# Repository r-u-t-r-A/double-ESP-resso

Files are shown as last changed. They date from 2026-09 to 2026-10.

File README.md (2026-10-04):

# double-ESP-resso

A cheap FPV race lap timer made from **two stacked Seeed XIAO ESP32-C5
boards** and no RX5808 module.

- The **RF node** turns the ESP32-C5's own 5 GHz Wi-Fi radio into a 5.8 GHz
  analog FPV power meter, using the receive path from
  [C5VRX](https://github.com/Twotoz/C5VRX).
- The **AP node** runs a port of [PhobosLT](https://github.com/phobos-/PhobosLT):
  a 2.4 GHz Wi-Fi access point, the web UI, lap detection, voice callouts and
  RSSI calibration. Voice callouts need an offline browser voice; see
  [docs/VOICE.md](docs/VOICE.md). Races can be started and stopped from an
  ExpressLRS radio button through its TX backpack; see
  [docs/RADIO_START.md](docs/RADIO_START.md).

```
 drone VTX ~~ 5.8 GHz ~~>  [ RF node  XIAO ESP32-C5 ]  MODEM_DIAG IQ -> power -> RSSI 0-255 @ 1 kHz
                                 |  D5/D9 UART, both directions
                           [ AP node  XIAO ESP32-C5 ]  PhobosLT lap logic + web UI
 phone / laptop <~~ 2.4 GHz Wi-Fi AP "PhobosLT_xxxxxx" ~~
```

The link is **two-way**. When you pick a band and channel in the web UI, the
AP node retunes the RF node. The RF gain is set the same way, from the
Calibration tab.

> **Status: experimental, not yet validated on hardware.**
> - **Tested:** both firmwares build, and the protocol and RSSI scaling pass
>   their host tests.
> - **Not yet measured:** tuning to R1/R3/R6/R7, RSSI behaviour during gate
>   passes, and desense from the AP radio.
>
> See [docs/bring-up.md](docs/bring-up.md) for the planned checks.

## Channels

The C5 radio can only be tuned from **5180 to 5885 MHz**.

| Band | Reachable | Not reachable |
|---|---|---|
| R (RaceBand) | R1 5658, R2, R3 5732, R4, R5, R6 5843, R7 5880 | R8 5917 |
| A / B / F | all | – |
| E | E1–E5 | E6–E8 |
| L | all (5362–5621), but these are far below the 5.66 GHz bootstrap center and untested | – |

Frequencies that fall between Wi-Fi channels are reached with the same
experimental `phy_set_freq()` step that C5VRX uses.

## Hardware

- 2 × Seeed Studio XIAO ESP32-C5.
- Optional:
  - A buzzer on the AP node's D8.
  - A 1S battery on the AP node's battery pads.
  - A **WS2812B strip around the gate** on the AP node's D4, with its own
    5 V supply. See [docs/hardware.md](docs/hardware.md#ws2812b-gate-led-strip-ap-node-d4).

**Join only these four pins between the boards:** 5V, GND, D5 and D9. The RF
node streams its 40–80 MHz IQ bus out on D0–D3 and D10, and D2/D3 are
strapping pins, so a full pin-to-pin stack is not safe. See
[docs/hardware.md](docs/hardware.md).

## Repository layout

| Path | What it contains |
|---|---|
| `rf-node/` | ESP-IDF v6.0.2 app for the RF node. GPL-3.0, derived from C5VRX. |
| `ap-node/` | PlatformIO / Arduino PhobosLT fork for the AP node. MIT, from PhobosLT. |
| `common/c5link_proto.h` | The shared UART line protocol (MIT). See [docs/protocol.md](docs/protocol.md). |
| `tools/rssi_log.py` | Records and plots RF node RSSI over USB, for calibration. |
| `tests/` | Host unit tests for the protocol and the RSSI scaling. |

## Documentation

| Document | Contents |
| --- | --- |
| [docs/FLASHING.md](docs/FLASHING.md) | Step-by-step flashing of both boards |
| [docs/hardware.md](docs/hardware.md) | Wiring, board stacking and the gate LED strip |
| [docs/protocol.md](docs/protocol.md) | RF node ↔ AP node UART protocol |
| [docs/bring-up.md](docs/bring-up.md) | Hardware bring-up checklist and results |
| [docs/VOICE.md](docs/VOICE.md) | Getting voice announcements working in the browser |
| [docs/RADIO_START.md](docs/RADIO_START.md) | Starting and stopping races from an ExpressLRS radio |

## Build and flash

Step-by-step flashing instructions for both boards are in **[docs/FLASHING.md](docs/FLASHING.md)**. The commands below are a short version.

Plug in **one board at a time**; the other board is powered through the 5V link.

### RF node

The RF node is an ESP-IDF v6.0.2 app. If you don't have ESP-IDF installed, use the container:

```sh
podman run --rm -v $PWD:/project:Z -w /project/rf-node docker.io/espressif/idf:v6.0.2 idf.py build
```

With ESP-IDF installed locally:

```sh
cd rf-node && idf.py set-target esp32c5 build flash monitor
```

### AP node

The AP node builds with PlatformIO:

```sh
cd ap-node
pio run -e XIAO_C5 -t upload          # firmware
pio run -e XIAO_C5 -t uploadfs        # web UI (LittleFS)
```

The `XIAO_C5` env uses the Tasmota `platform-espressif32` 2026.05.50 build,
which ships Arduino core 3.3.8 with ESP32-C5 support. The original PhobosLT
envs (`PhobosLT`, `ESP32C3`, `ESP32S3`) are kept for reference. They currently
fail to build upstream as well, because the old AsyncTCP fork no longer
matches newer ESPAsyncWebServer releases.

### Host tests

```sh
cc -std=c99 -Wall -Wextra -Werror -I common tests/test_c5link_proto.c -o /tmp/t_proto && /tmp/t_proto
cc -std=c99 -Wall -Wextra -Werror -I rf-node/main tests/test_rssi_scale.c -lm -o /tmp/t_rssi && /tmp/t_rssi
cc -std=c99 -Wall -Wextra -Werror -I ap-node/lib/ELRSBACKPACK tests/test_elrs_msp.c -o /tmp/t_elrs && /tmp/t_elrs
cc -std=c99 -Wall -Wextra -Werror -I ap-node/lib/LEDSTRIP tests/test_ledstrip_timing.c -o /tmp/t_led && /tmp/t_led
```

## Using it

1. Power the stack and join Wi-Fi `PhobosLT_xxxxxx` (password `phoboslt`).
   Then open `http://20.0.0.1`.
2. **Configuration tab:** pick the band and channel (for example R1, R3, R6 or
   R7) and press *Save Configuration*. The *RF node* line should show
   `OK <MHz> MHz …` within a second.
3. **Calibration tab:** watch the live RSSI while you fly or carry the quad
   through the gate.
   - If the peak flat-lines at 255, lower the *RF node gain*.
   - Set *Enter* just below the gate-pass peak and *Exit* well above the
     far-away level, then save.
4. **Race tab:** press *Start Race*.

For finer calibration without the AP node, plug the RF node in over USB and run:

```sh
tools/rssi_log.py /dev/ttyACM0 --freq 5732 --gain 40 --seconds 60 -o pass.csv
tools/rssi_log.py --plot pass.csv
```

## Gate lights

With a WS2812B strip fitted, the gate shows the race state. States higher in
the table take priority.

| State | Lights |
|---|---|
| RF node link down or RF error | Purple blink |
| Lap recorded | Three white segments chase around the ring (0.6 s) |
| Race start (tone) | Bright green flash (1 s) |
| Start countdown ("Arm your quad") | Pulsing red. Times out after 15 s if the start never comes. |
| Race running | Green. White while the drone is inside the gate (RSSI ≥ Enter). |
| Idle | Breathing blue, plus an RSSI level meter that fills from *Exit* to *Enter* (useful for calibration) |
| Low battery | Short amber blip every 2 s, over any state |

The start countdown itself still runs in the browser. *Start Race* posts
`/timer/arm`, and the gate turns green when the page posts `/timer/start` at
the tone.

## How the RF node measures RSSI

The RF node brings the ESP32-C5 Wi-Fi PHY up **receive-only**, the same way as C5VRX:
- Packet AGC is disabled and a fixed gain index is forced.
- MODEM_DIAG is routed to GPIOs.
- PARLIO RX captures the Q4/I4 sample bus at 40 MS/s.

Every millisecond it:
1. Captures one 4096-sample window (about 102 µs).
2. Computes the mean I² + Q², treating each 4-bit code as the centre of its
   quantizer bucket.
3. Maps that power logarithmically to 0–255, about 10.8 counts per dB across
   the roughly 23.5 dB range available at one gain.

This is not calibrated dBm. Lap timing only needs a repeatable relative peak,
and PhobosLT's per-sample Kalman filter and enter/exit detection work on it
unchanged.

The C5VRX composite-video path is not used at all. For power measurement
there is no need for gapless sampling, demodulation or the DAC.

## Licensing

- **`rf-node/`** contains code derived from C5VRX and is licensed
  **GPL-3.0-or-later** (see `LICENSE`).
- **`ap-node/`** is derived from PhobosLT and stays **MIT**. The original
  copyright notice is kept in `ap-node/LICENSE`.
- **`common/c5link_proto.h`** is MIT, so both nodes can use it.

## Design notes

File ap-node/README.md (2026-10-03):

# AP node: PhobosLT for the double-ESP-resso RF node

This is a fork of [PhobosLT](https://github.com/phobos-/PhobosLT) at upstream
commit `142cf08`, MIT licensed. The upstream README is kept as
`UPSTREAM_README.md`.

## What the `XIAO_C5` env changes

Everything is behind `-DC5VRX_LINK`, so the upstream environments are unchanged.

- **`lib/C5LINK/`** (new): an RSSI source that reads the RF node over UART1
  (RX D5/GPIO24, TX D9/GPIO9). Its interface matches the `RX5808` class:
  - `readRssi()` returns the latest RSSI sample.
  - `handleFrequencyChange()` retunes the RF node.
  - It adds `handleGainChange()`, a non-blocking `poll()`, and link status.
  - The protocol itself is in `../common/c5link_proto.h`.
- **`lib/LAPTIMER`**: works with either source through `typedef … RssiSource`.
- **`src/main.cpp`**: runs one `LapTimer` update per 1 kHz RF sample, and
  yields every millisecond so both tasks get CPU time on the single-core C5.
- **`lib/CONFIG`**:
  - XIAO C5 pin block.
  - New `rfGain` setting. `CONFIG_VERSION` is bumped to 1, so saved settings
    reset once.
  - The default frequency is R1 (5658 MHz).
- **`lib/WEBSERVER`**:
  - The Wi-Fi AP/STA is forced to 2.4 GHz only, at 11 dBm.
  - `/status` shows an `RF Node:` line.
- **`lib/LEDSTRIP/`** (new):
  - Drives the WS2812B gate lights on `PIN_LED_STRIP` (D4) using Adafruit
    NeoPixel over RMT.
  - Renders from the background task at 50 Hz.
  - Colours depend on race state, laps, RSSI, RF link health and the battery alarm.
- **`lib/CONFIG`** also stores `ledOn`, `ledCount` and `ledBright`, with
  `CONFIG_VERSION` bumped to 2.
  - Version 3 appends `elrsOn` and the ELRS backpack UID; v2 settings are kept.
- **`lib/RACECONTROL/`** (new): runs the start countdown on the node.
  - It arms the gate, waits for the spoken lead-in plus a random 1–5 s, then
    starts the lap timer.
  - It reports `raceArm` / `raceStart` / `raceStop` as SSE events.
- **`lib/ELRSBACKPACK/`** (new, `-DELRS_BACKPACK`): starts and stops races
  from an ExpressLRS radio button via the TX backpack's ESP-NOW messages. See
  [../docs/RADIO_START.md](../docs/RADIO_START.md).
- **`lib/WEBSERVER`** adds:
  - `POST /timer/begin`, which starts the firmware countdown. `/timer/stop` also
    cancels a countdown.
  - `POST /timer/arm`, which turns the gate red during the countdown. It's kept
    for the old browser countdown.
  - In AP mode, the SoftAP runs on channel 1 as `WIFI_AP_STA`, for ESP-NOW.
- **`data/`** (web UI):
  - Shows the RF node status and an RF gain field. These appear only when
    `/config` includes `rfGain`.
  - Warns about channels the C5 can't tune.
  - LED strip settings.
  - *Start Race* posts `/timer/begin` when `/config` includes `raceCtl`, and
    otherwise runs the old browser countdown.
  - ELRS radio-start settings, shown only when `/config` includes `elrsUid`.

## Build

```sh
pio run -e XIAO_C5 -t upload
pio run -e XIAO_C5 -t uploadfs
```

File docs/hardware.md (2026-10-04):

# Hardware

The timer uses two Seeed Studio XIAO ESP32-C5 boards, stacked. One is the
**RF node** and the other is the **AP node**.

## XIAO ESP32-C5 header

| Pin | D0 | D1 | D2 | D3 | D4 | D5 | D6 | D7 | D8 | D9 | D10 |
|-----|----|----|----|----|----|----|----|----|----|----|-----|
| GPIO | 1 | 0 | 25 | 7 | 23 | 24 | 11 | 12 | 8 | 9 | 10 |

## What each board drives

The RF node:

| Pins | Use |
|---|-----|
| D0, D1, D2, D3, D10 and GPIO 3/4/5 (not on the header) | **MODEM_DIAG Q4/I4 outputs**, toggling at 40–80 MHz |
| D5 (GPIO24) | UART TX to the AP node |
| D9 (GPIO9) | UART RX from the AP node |

The AP node:

| Pins | Use |
|---|-----|
| D5 (GPIO24) | UART RX from the RF node |
| D9 (GPIO9) | UART TX to the RF node |
| D8 (GPIO8) | Optional buzzer |
| GPIO27 | User LED |
| GPIO6 / GPIO26 | Battery sense ADC / divider enable |

## Stacking rule: join 5V, GND, D5 and D9 only

When XIAO boards are stacked, each pin meets the same pin on the other board.
Joining **all** pins is not safe, for two reasons:

- The RF node's IQ bus on D0–D3 and D10 would be loaded by the AP node's pins
  and would radiate over a longer trace.
- D2 (GPIO25) and D3 (GPIO7) are ESP32-C5 strapping pins. If the AP node
  resets while the RF node is driving them, the AP node can boot in the wrong
  mode.

**Do not use D6/D7 for the link.** GPIO11/12 are the ESP32-C5 UART0 console
pins. Both chips' ROM boot logs, and the AP node's whole Arduino console, are
driven out on GPIO11. On the first hardware test this fought the RF node's
transmitter, and every link line arrived garbled.

Fit header pins only at **5V, GND, D5 and D9**, or wire those four pins
directly. Because the pins meet pin-to-pin, the UART roles cross in firmware:

```
RF node D5 (TX) ─────── D5 (RX) AP node
RF node D9 (RX) ─────── D9 (TX) AP node
RF node 5V      ─────── 5V      AP node
RF node GND     ─────── GND     AP node
```

## Power

One USB-C cable or a battery powers both boards through the 5V link.

- To flash a board, plug in **only that board's** USB cable.
- The XIAO's VBUS back-feed protection has not been verified, so don't
  connect two USB hosts at once.

## RF considerations

- The AP node runs its Wi-Fi AP on 2.4 GHz only, at 11 dBm, a few millimetres
  from a 5.8 GHz receiver. The two bands are far apart, but desense has not
  been measured yet (see `bring-up.md`).
- The RF node uses the board's own antenna path. The RF and AP boards should
  ideally use antennas pointing away from each other.

## Unverified details

- The XIAO ESP32-C5 battery-sense divider ratio and enable polarity. The
  firmware drives GPIO26 high and assumes a 1:2 divider.
- Whether the XIAO user LED is active-low. The firmware assumes it is.

## WS2812B gate LED strip (AP node, D4)

The AP node drives a single-wire RGB strip around the gate on **D4 (GPIO23)**.
D4 is not joined to the RF node.

Supported chips, selected in the web UI (Configuration tab, **LED chip** and
**LED colour order**):

| Chip | Speed | Usual colour order | Notes |
|---|---|---|---|
| WS2812B | 800 kHz | GRB | The default. 5 V, one LED per chip. |
| WS2812 | 800 kHz | GRB | Older 6-pin version, slightly different timing. |
| WS2811 (800 kHz) | 800 kHz | RGB, but varies by strip | Often 12 V strips where one chip drives a group of 3 LEDs. Set **LED count** to the number of chips, not LEDs. |
| WS2811 (400 kHz) | 400 kHz | RGB | Only for chips wired for low-speed mode. A 300-chip frame then takes 18 ms. |

If the colours are wrong, set the strip to idle (breathing blue) and change
**LED colour order** until it really is blue.

The diagram below is for a 5 V strip. For a 12 V WS2811 strip, use a 12 V supply
for the strip and keep the common ground.

```
5 V supply (+) ──┬───────────────────── strip +5V
                 └─ 1000 µF ─┐
5 V supply (−) ──┴───────────┴───────── strip GND ── AP node GND
AP node D4 ── 330 Ω ─────────────────── strip DIN
```

- **Power the strip from its own 5 V supply**, for example a buck converter
  from the flight battery. A XIAO's USB or 5V pin cannot supply it.
  - Tie the supply ground to the AP node's GND.
  - Put the capacitor right at the strip input.
- **Sizing the supply:** a 50 cm diameter gate is about 157 cm around. That is
  about 94 LEDs at 60/m, or 47 at 30/m. Each LED draws up to 60 mA at full
  white.

| Case | Current |
|---|---|
| 94 LEDs, full brightness, white | 5.6 A |
| 94 LEDs, default brightness cap 80/255, white | about 1.8 A |
| Racing green at the default cap | about 0.5 A |

  Size the supply for the brightness you configure.
- **Level shifting:** WS2812B and WS2811 need about 0.7 × their supply on the
  data line, which is 3.5 V at 5 V, so 3.3 V data is just under spec.
  - It usually works with a short data wire.
  - If the first LEDs flicker or show wrong colours, add a 74AHCT125 level
    shifter powered from 5 V.
  - Use the shifter from the start for 12 V WS2811 strips.
- **Keep it away from the RF node:** route the strip's supply and its wiring
  away from the RF node. Rerun the desense check (bring-up §3) with the strip lit.
- **Powering the XIAO stack from the strip supply:** only feed the stack's 5V
  pin from that supply when no USB cable is plugged in.

The LED chip, colour order, LED count, brightness cap and on/off switch are set
in the web UI (Configuration tab). The colour meanings are listed in `README.md`.

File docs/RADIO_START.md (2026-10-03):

# Start and stop races from an ExpressLRS radio

You can start a race with a button on your radio, so you don't have to press
*Start Race* on a laptop and then rush to put on your goggles.

- **Short press** (under 1 s): starts the race countdown. You hear "Arm your
  quad / Starting on the tone in less than five", then the tone 1–5 s later.
- **Long press** (hold for 1 s): stops the race, or cancels the countdown.

The AP node buzzer chirps when it recognises a press.

No extra receiver is needed. The ExpressLRS TX module's built-in **TX
backpack** sends the radio's *DVR Rec* switch over ESP-NOW, and the AP node
listens for it. This is the same message RotorHazard's Timer backpack uses.

## Requirements

- ExpressLRS TX firmware **2.3.0 or newer**, with a TX backpack. This covers
  most current TX modules and radios with internal ELRS, which have an
  ESP8285/ESP32 backpack chip.
- TX backpack firmware bound to a known bind phrase (step 1).
- The AP node in its own **access point mode** (the default, with no home Wi-Fi
  SSID configured). ESP-NOW from the backpack is fixed on Wi-Fi channel 1, so
  radio start doesn't work while the timer is joined to a home network.

## 1. Bind the TX backpack to your bind phrase

The timer needs the bind phrase the backpack uses. Use your normal ELRS bind
phrase, the one your TX and receivers use.

- **Flash it in:** in the ExpressLRS Configurator, open the **Backpack** tab,
  pick your TX module's backpack target, enter the **same bind phrase**, and
  flash it. On radios with internal ELRS this is usually done over Wi-Fi.
- **Or bind it:** if the backpack was flashed without a bind phrase, press
  **Bind** in the ELRS Lua script. The TX hands its own UID, which comes from
  its bind phrase, to the backpack.

## 2. Set up the button on the radio (EdgeTX)

1. Pick a free AUX channel. ELRS numbers them from channel 5: **AUX1 = CH5**,
   AUX2 = CH6, …, AUX8 = CH12.
2. **Model → Mixes**, on that channel: Source = a **momentary** switch or button,
   for example **SH** on Radiomaster radios. Weight 100, offset 0.
3. Check on the **Channel Monitor** that the channel is **-100 when released**
   and **+100 while pressed**. If it's the other way round, set the weight to
   -100.

## 3. Turn on DVR Rec in the ELRS Lua script

Open **Tools → ExpressLRS → Backpack**:

| Setting | Value |
| --- | --- |
| Backpack | **On** |
| DVR Rec | **AUX n ▲** for the channel from step 2, where ▲ = "on" when the channel is high |
| DVR Srt Dly | **0s** |
| DVR Stp Dly | **0s** |

The delays don't affect the timer, which reacts to each press straight away.
They only delay goggle DVR recording.

If **DVR Rec** uses the wrong polarity (▼), the timer sees the button as
held all the time. Every release then looks like a new hold, and races stop or
won't start. Fix it by choosing ▲ or inverting the mix in step 2.

## 4. Enter the bind phrase on the timer

1. Connect to the timer's Wi-Fi and open the web UI.
2. **Config** tab:
   - **Radio start (ELRS):** tick it.
   - **ELRS bind phrase:** type the phrase from step 1. The timer stores only
     the 6-byte UID hashed from it, never the phrase. Leave the field empty to
     keep the current UID.
3. Click **Save Configuration**. **ELRS backpack UID** now shows the address
   the timer listens on, for example `4e:04:fd:82:21:55` for the phrase `test`.
4. Open `http://20.0.0.1/status`. The line `ELRS Backpack:` should read
   `listening`.

## 5. Test

1. With the web UI open on the **Race** tab and voice enabled (see
   [VOICE.md](VOICE.md)), short-press the button on the radio.
2. The AP buzzer chirps and the gate turns red. The browser says "Arm your quad
   …", and the tone follows.
3. Hold the button for 1 s. The race stops and the browser says "Race stopped".

The web UI's *Start Race* button uses exactly the same countdown on the timer,
so the button and the radio behave the same way.

## Troubleshooting

`http://20.0.0.1/status` shows an ELRS block under `ELRS Backpack:`. The AP
node's USB serial log (460800 baud) prints the same block every 10 s. Press the
radio button a few times, reload the page, and work down the list:

| Line | What it tells you |
| --- | --- |
| `Start errors` | All three should be `0`. A non-zero `mac` or `esp_now` value means ESP-NOW couldn't start on the C5. |
| `UID … (STA MAC …, channel …)` | The STA MAC must equal the UID, and the channel must be `1`. |
| `On air` | Every ESP-NOW frame the timer hears on its channel, from any device. **0** means the backpack isn't transmitting on channel 1: check that Backpack is On, DVR Rec is set, and the TX firmware is 2.3.0 or newer. |
| `On air … last A -> B` | The backpack's real UID. If `B` differs from `UID`, the bind phrases differ: rebind the backpack or fix the phrase on the timer. |
| `Received` | Frames ESP-NOW delivered to the timer. If `On air` counts up but this stays at 0, the STA MAC override isn't taking effect. |
| `From UID` / `MSP ok` | Frames from the bound backpack, and the ones that parsed. |
| `DVR switch` | Recording-state messages. If other functions arrive (`last function`) but none of these, the DVR Rec AUX setting isn't sending. |
| `Presses` | Classified presses. If presses are counted but the race doesn't start, the timer was already running or counting down. |

## Notes and limitations

- **One message per press edge.** The backpack sends each change once, without
  repeats. If a press is missed, press again.
  - A lost "release" makes a press look long, so it can only stop or cancel a
    race, never start one by accident.
- **Goggles with a VRx backpack** bound to the same phrase also start and stop
  DVR recording on every press.
  - With a short press, recording stops again straight away. If you want DVR
    of the race, start recording in the goggles yourself.
- **AP mode only.** If a home Wi-Fi SSID is configured and the timer joins
  that network, `/status` shows `not running (AP mode only)`.
- **Wi-Fi channel.** The timer's own Wi-Fi access point is fixed on channel 1,
  to match the backpack.

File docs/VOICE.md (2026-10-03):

# Voice announcements

The web UI speaks lap times through the browser's own text-to-speech (the Web
Speech API, wrapped by `ap-node/data/articulate.min.js`). Nothing is synthesised
on the ESP32. The start tone is different: it is generated with Web Audio, so it
plays even when voice is broken.

Voice needs two things:

1. Voice turned on in the web UI, every time the page is loaded.
2. A text-to-speech voice in the browser that works **without internet**. The
   timer's Wi-Fi AP has no internet, so Chrome's online "Google …" voices stay
   silent without any error.

## 1. Turn voice on in the web UI (every device)

1. Connect to the timer's Wi-Fi and open the web UI.
2. **Config** tab, **Announcer Type**: choose **Lap Time**, **2 Consecutive
   Laps Time** or **3 Consecutive Laps Time**. **Beep** and **None** don't
   speak lap times.
3. Click **Save Configuration**.
4. Click **Enable voice**.
5. Click **Test voice**. You should hear "testing sound for pilot …, 1, 2, 3".

The **Enable voice** setting is not saved. Click it again after every page
reload, or no announcements are spoken. Until you click it, the start tone is
the only sound.

## 2. Fedora Linux, Google Chrome

Chrome on Linux only uses the system speech engine (speech-dispatcher) when it
is started with `--enable-speech-dispatcher`. Without that flag Chrome offers
only its online voices.

### 2.1 Install and check the speech engine

```sh
sudo dnf install speech-dispatcher speech-dispatcher-espeak-ng espeak-ng
spd-say -w "lap timer test"
```

You must hear "lap timer test". If you hear nothing, fix the system audio or
speech-dispatcher first. Chrome can't speak if this doesn't.

### 2.2 Start Chrome with the flag (one-off test)

1. Quit Chrome completely: close every window and check `pgrep -a chrome`
   prints nothing. Chrome ignores the flag if an instance is already running.
2. Run:

   ```sh
   google-chrome-stable --enable-speech-dispatcher
   ```

### 2.3 Make the flag permanent

The Chrome launcher (`/opt/google/chrome/google-chrome`) doesn't read a flags
file, so override the desktop launcher in your home directory instead:

```sh
mkdir -p ~/.local/share/applications
for f in google-chrome.desktop com.google.Chrome.desktop; do
  [ -f /usr/share/applications/$f ] || continue
  sed 's|^Exec=/usr/bin/google-chrome-stable|Exec=/usr/bin/google-chrome-stable --enable-speech-dispatcher|' \
    /usr/share/applications/$f > ~/.local/share/applications/$f
done
update-desktop-database ~/.local/share/applications
```

Log out and back in, or quit Chrome fully, then start it from the app menu.
Chrome updates won't overwrite these copies. To undo the change, delete the two
files from `~/.local/share/applications`.

### 2.4 Check that Chrome sees offline voices

On the timer web UI, open DevTools (F12) → **Console** and run:

```js
speechSynthesis.getVoices().filter(v => v.localService).map(v => v.name + " (" + v.lang + ")")
```

- **Non-empty list** (espeak-ng voices such as `English (America)+…`): the flag
  works. Do section 1 and test.
- **Empty list**: Chrome wasn't started with the flag. Repeat 2.2 and make sure
  no old Chrome process was still running.

To see which voice Chrome uses by default:

```js
speechSynthesis.getVoices().find(v => v.default)
```

If the default voice has `localService: false`, the web UI will still try that
online voice and stay silent while you're on the timer's Wi-Fi. If that
happens, record it in `docs/bring-up.md`; the web UI code then needs to choose
a local voice itself.

## 3. Android, Google Chrome

Chrome on Android uses the phone's text-to-speech engine. It works offline only
if the voice data for your language is downloaded.

1. **Settings → System → Languages (& input) → Text-to-speech output**. The
   path differs by manufacturer; search Settings for "text-to-speech" if you
   can't find it.
2. Set **Preferred engine** to **Speech Services by Google**. On Samsung phones
   the Samsung engine also works if its English voice is downloaded.
3. Tap the gear icon next to the engine → **Install voice data** → **English
   (United States)** (or your language), and download it. Choose a voice
   **without** a cloud/network icon.
4. Turn the **Speech rate** and **Pitch** sliders back to the middle if they were
   changed. The web UI also has its own **Announcer Rate** setting.
5. Test offline: turn on airplane mode, then turn Wi-Fi back on and connect to
   the timer's AP. Tap **Play** (or **Listen to an example**) on the
   Text-to-speech screen. If this is silent, the web UI will be too.
6. Turn up the **media** volume. Speech uses media volume, not ringer volume.
7. When Android warns "This network has no internet access", choose **Stay
   connected**. Otherwise the phone may switch to mobile data and lose the
   timer page.
8. Open the web UI in Chrome and follow section 1.

Optional check: in Chrome, open `chrome://inspect` on the laptop with the phone
connected over USB debugging, and run the console commands from section 2.4.

## 4. Quick troubleshooting

| Symptom | Cause |
| --- | --- |
| Only the start tone, no "Arm your quad" | **Enable voice** wasn't clicked after the page loaded (section 1). |
| "Arm your quad" works but no lap times | **Announcer Type** is **None** or **Beep**. |
| **Test voice** is silent on Fedora | Chrome was started without `--enable-speech-dispatcher` (section 2). |
| **Test voice** is silent on Android | No offline voice data installed, or media volume is down (section 3). |
| Voice works on home Wi-Fi but not on the timer's Wi-Fi | An online voice is in use (sections 2.4 and 3.3). |

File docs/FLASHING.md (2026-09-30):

# Flashing double-ESP-resso

The two boards run different firmware:

| Board | Firmware | Build tool |
|---|---|---|
| **AP node** | PhobosLT fork (`ap-node/`) | PlatformIO |
| **RF node** | `rf-node/` | ESP-IDF v6.0.2, via the container below |

## Before you start

- **Label the boards.** Both are identical Seeed XIAO ESP32-C5s. Put an **AP**
  and an **RF** sticker on them before flashing.
- **Plug in only the board you are flashing.** When the boards are stacked,
  the other board is powered through the 5V link. Two USB hosts must not be
  connected at the same time.
- On Linux the board appears as `/dev/ttyACM0` when it is the only one plugged
  in. Check with `ls /dev/ttyACM*`. Your user needs access to the port (the
  `dialout` group on most distros).
- Close any serial monitor on the port before flashing.

**Tools**

- [PlatformIO Core](https://docs.platformio.org/en/latest/core/installation/) (`pio`).
  It also provides `esptool`.
- To build the RF node, either:
  - [Podman](https://podman.io/) or Docker with the `docker.io/espressif/idf:v6.0.2` image, or
  - a local ESP-IDF v6.0.2 install.

All commands below run from the repository root unless a `cd` says otherwise.

## 1. AP node

PlatformIO builds the firmware and picks the files and flash addresses itself.
Run both commands: the first writes the firmware, the second writes the web UI.

```sh
cd ap-node
pio run -e XIAO_C5 -t upload   --upload-port /dev/ttyACM0   # firmware
pio run -e XIAO_C5 -t uploadfs --upload-port /dev/ttyACM0   # web UI (LittleFS)
```

<details>
<summary>What gets written, for flashing manually with esptool</summary>

Files are in `ap-node/.pio/build/XIAO_C5/`:

| Address | File |
|---|---|
| `0x2000` | `bootloader.bin` |
| `0x8000` | `partitions.bin` |
| `0xe000` | `boot_app0.bin` (from the Arduino core: `~/.platformio/packages/framework-arduinoespressif32/tools/partitions/boot_app0.bin`) |
| `0x10000` | `firmware.bin` |
| `0x670000` | `littlefs.bin` (built with `pio run -e XIAO_C5 -t buildfs`) |

Flash mode is DIO, flash size is 8 MB and flash frequency is 80 MHz. The
partition layout is Arduino `default_8MB.csv`.

</details>

**Check the AP node**

1. Press **RESET**.
2. A Wi-Fi network `PhobosLT_xxxxxx` appears. The password is `phoboslt`.
3. Join it and open `http://20.0.0.1`.

The *RF node* line shows `DOWN`, and a connected LED strip blinks purple,
until the RF node is flashed and stacked. That is expected at this stage.

After the first flash, and after any firmware that changes the config format,
the saved settings reset to defaults once.

## 2. RF node

Unplug the AP node and plug in the RF node.

> **Enter download mode by hand.** While the RF node firmware is running, its
> USB serial port does not respond (see *Known issue* below), so esptool's
> automatic reset fails with `Write timeout`. Before every RF node flash:
> hold **BOOT**, tap **RESET** (or replug USB), then release BOOT.

**Build.** Pick the command for your setup:

```sh
# with Podman (use `docker` instead of `podman` for Docker)
podman run --rm -v $PWD:/project:Z -w /project/rf-node docker.io/espressif/idf:v6.0.2 idf.py build

# or with a local ESP-IDF v6.0.2
cd rf-node && idf.py set-target esp32c5 build && cd ..
```

**Flash.** This uses the esptool bundled with PlatformIO:

```sh
cd rf-node
~/.platformio/penv/bin/python -m esptool --chip esp32c5 -p /dev/ttyACM0 -b 921600 \
  --before no_reset --after watchdog_reset \
  write_flash --flash_mode dio --flash_size 8MB --flash_freq 80m \
  0x2000  build/bootloader/bootloader.bin \
  0x8000  build/partition_table/partition-table.bin \
  0x10000 build/rf-node.bin
```

With a local ESP-IDF you can run `idf.py -p /dev/ttyACM0 flash` from `rf-node/`
instead.

Use the underscore spelling (`write_flash`, `--flash_mode`) shown above.
PlatformIO may install esptool v4 or v5 depending on which platform ran last,
and only the underscore form works in both.

| Address | File (in `rf-node/build/`) |
|---|---|
| `0x2000` | `bootloader/bootloader.bin` |
| `0x8000` | `partition_table/partition-table.bin` |
| `0x10000` | `rf-node.bin` |

The same list is in `rf-node/build/flasher_args.json` after a build.

`--after watchdog_reset` starts the new firmware straight away. Pressing
RESET afterwards works too.

**Check the RF node** through the AP node (step 3): the web UI's *RF node*
line must show `OK <MHz> MHz gain <g> fw 1 samples …`, with `samples`
climbing by about 1000 per second.

**Known issue: the RF node's USB console.** On the first hardware test
(2026-09-30) the RF node sent nothing over USB and never read input, even
before any radio code ran and with the official USB-Serial-JTAG driver
installed. The node itself runs normally; its boot trace in NVS showed that.
This is still being investigated. Until it is fixed, `tools/rssi_log.py` and
the console commands below do not work; use the AP node's Calibration tab.

Console commands (for when USB works):

| Command | Action |
|---|---|
| `f <mhz>` | Tune |
| `g <gain>` | Set fixed gain (0–89) |
| `r` | Toggle the RSSI CSV stream (used by `tools/rssi_log.py`) |
| `d` | Diagnostics: boot stage and capture counters |
| `t` | Boot trace saved in NVS |

## 3. Stack and run

1. Join only **5V, GND, D5 and D9** between the boards (see `docs/hardware.md`).
2. Power the stack from **one** USB cable, or from the battery.
3. Open `http://20.0.0.1`. Within about a second the *RF node* line changes to
   `OK 5658 MHz gain 40 …`.

Continue with `docs/bring-up.md` for the hardware checks.

## Troubleshooting

- **No serial port, or the connection fails:**
  1. Hold **BOOT**.
  2. Tap **RESET**, or replug the USB cable while holding BOOT.
  3. Release BOOT and run the flash command again.

  Press RESET afterwards to start the new firmware.
- **Port is busy:** close `pio device monitor`, `idf.py monitor` or any other
  serial terminal.
- **Permission denied on `/dev/ttyACM0`:** add your user to the `dialout`
  group, then log out and back in.
- **Wiping a board completely**, for example one that previously ran other
  firmware: add this before flashing:

  ```sh
  ~/.platformio/penv/bin/python -m esptool --chip esp32c5 -p /dev/ttyACM0 erase_flash
  ```

  This also clears the RF node's saved channel and gain, and the AP node's settings.
- **`Handler did not handle the request` at `http://20.0.0.1`:** the web UI
  filesystem did not mount. The serial log shows `Mounting LittleFS failed`.
  - The ESP32-C5 Arduino core only mounts LittleFS **disk version 2.0**, and
    the platform builds 2.1 images by default. `targets/XIAO_C5.ini` sets
    `board_build.littlefs_version = 2.0`.
  - Pull the latest repo and run the `uploadfs` step again.
- **Web UI missing or showing old pages** after an AP firmware update: run the
  `uploadfs` step again.
- **RF node shows `DOWN` in the web UI:**
  - **UART wiring:** the roles are crossed **in firmware**, so do **not**
    cross the wires. Connect D5 to D5 and D9 to D9, straight through, the same
    way stacked headers line up.
  - **RF node firmware:** check it on its own over USB (`s` must reply
    `STATUS,…`).
  - **Power:** check that the boards share GND and 5V.

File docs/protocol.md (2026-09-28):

# RF node ↔ AP node UART protocol

The protocol is defined in [`common/c5link_proto.h`](../common/c5link_proto.h)
and tested in [`tests/test_c5link_proto.c`](../tests/test_c5link_proto.c).

## Framing

- UART runs at 921600 baud, 8N1, with no flow control.
- Messages are ASCII lines: `<payload>*<HH>\n`.
- `HH` is the upper-case hex XOR of all payload bytes, as in NMEA.
- The receiver drops lines that fail the checksum or have a bad field, and
  resynchronises on the next `\n`.

## Messages

| Direction | Line | Meaning |
|---|---|---|
| RF → AP | `R,<seq>,<rssi>` | One RSSI sample: `seq` 0–255 wraps, `rssi` 0–255. Sent at 1 kHz, about 14 bytes each, so ~140 kbit/s. |
| RF → AP | `S,<mhz>,<gain>,<state>,<fw>` | Status. Sent on boot, after every command, and once a second as a heartbeat. |
| AP → RF | `F,<mhz>` | Tune. The RF node accepts 5180–5885 MHz. |
| AP → RF | `G,<gain>` | Fixed RX gain index, 0–89. |
| AP → RF | `Q` | Ask for status. |

`<state>` is one of the following:

| State | Meaning |
|---|---|
| `OK` | Measuring on `<mhz>`. |
| `TUNING` | A retune is in progress. No `R` lines are sent. |
| `ERR_FREQ` | The requested frequency is outside the tunable window. The RF node stays on `<mhz>` but sends no `R` lines, so a wrong channel is never timed. |
| `ERR_RF` | The PHY retune failed. |

Example:

```
R,17,142*63
S,5732,40,OK,1*61
F,5843*60
```

## Ownership and recovery

- **The AP node owns the configuration.** The frequency and gain are stored in
  its PhobosLT config, set from the web UI.
- **The AP node resends until the RF node agrees.** Its `parallelTask` compares
  them with the last `S` line and resends `F` or `G` every 250 ms until they
  match. After `ERR_FREQ` or `ERR_RF` it backs off to every 2 s.
  - If the RF node reboots, the AP node reapplies the settings within about 1 s.
- **The RF node remembers its last settings.** It saves the last good
  frequency and gain in NVS, so it keeps measuring without an AP node, for
  example for USB calibration.
- **Lost samples are counted.** Gaps in `seq` are counted as dropped samples.
  They appear with the link state on the web UI's *RF node* line (`/status`).

## Timing

- The AP node runs one PhobosLT `LapTimer` update per received `R` sample. The
  Kalman filter therefore always sees a fixed 1 kHz input rate, and the
  lap-timer loop's own speed doesn't matter.
- Peak times are taken from the AP node's `millis()` when a sample is
  processed. UART transport and batching add a nearly constant 1–2 ms, which
  cancels out of lap times because each lap is measured peak to peak.

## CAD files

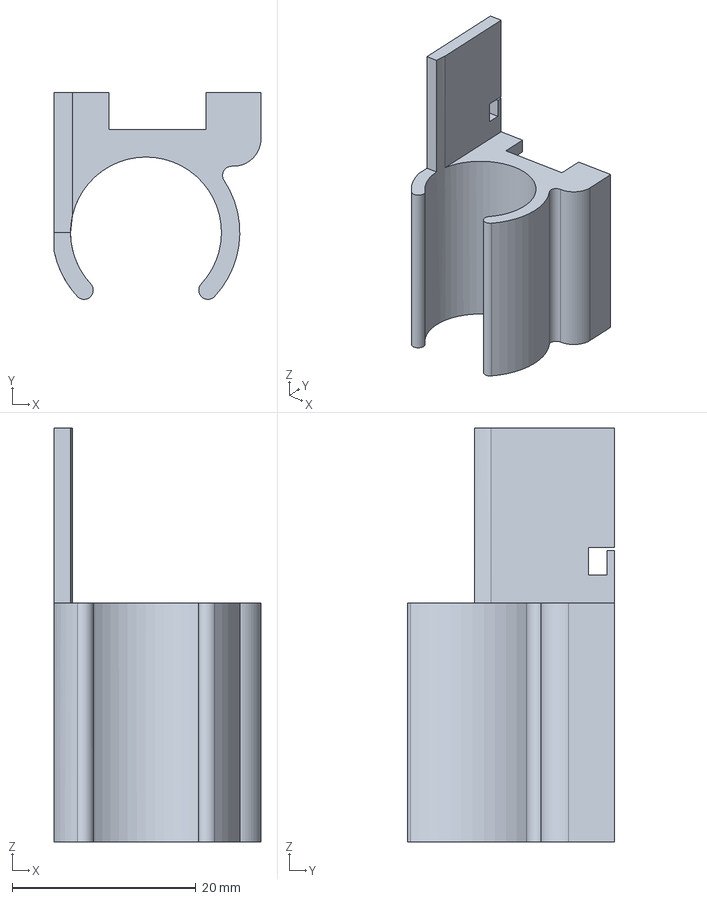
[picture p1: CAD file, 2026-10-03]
double-ESP-resso.FCStd
22.5 x 22.5 x 45.0 mm

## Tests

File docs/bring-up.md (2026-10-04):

# Hardware bring-up checklist

Record the results here (with dates) as they are measured.

## Results so far

**2026-09-30, first hardware session**
- **AP node:**
  - The web UI failed until the LittleFS image was built as disk version 2.0.
  - The link initially failed because D6/D7 carry the C5's UART0 console on
    both boards. It was moved to D5/D9.
- **RF node:**
  - **Capture:** the finite per-sample PARLIO receive starved the CPU after
    the first capture. It was replaced with C5VRX's interrupt-free continuous
    ring.
  - **Memory:** the MAC dump window 0x40830000–0x4083FFFF is now reserved
    from the heap.
- **Link:** works. The AP shows `OK 5880 MHz gain 40 fw 1`, with about 1000
  samples/s and no drops after startup.
- **RSSI:** reads 0 with no transmitter on the channel. It responds with a VTX
  on the channel and more gain ("works somewhat"). It is not calibrated yet.
- **Open issue:** the RF node's USB console stays silent (see [FLASHING.md](FLASHING.md)).

## 1. RF node alone (USB)

- [ ] Flash the RF node. The boot log shows `RF ready: <MHz> MHz, gain <g>` and `RF node v1 running`.
- [ ] Type `s` and check the reply `STATUS,<mhz>,<gain>,OK,1`.
- [ ] Tune each channel with a VTX powered on nearby. Each must reply `OK` and the RSSI must rise with the VTX on:
  - [ ] `f 5658` (R1)
  - [ ] `f 5732` (R3)
  - [ ] `f 5843` (R6)
  - [ ] `f 5880` (R7)
- [ ] `f 5917` (R8) must reply `ERR_FREQ`.
- [ ] Measure the noise floor with no VTX: `tools/rssi_log.py … --seconds 20`. Record the RSSI mean and spread.
- [ ] Take gate-pass traces at several gains (for example 20 / 30 / 40 / 50). Pick the default gain where:
  - the pass peak stays below 255 and clipping stays low;
  - the far-away level is well above the noise floor.
- [ ] Adjacent channel: with the node on R3 and a second VTX on R1 or R4 at the gate, the R3 RSSI must not reach the enter threshold.
- [ ] If a finite PARLIO receive fails or times out (`iq_power_measure` errors), switch to C5VRX's infinite-ring capture instead: `get_completed_rx_sample_window()` in C5VRX `main/video.c`.

## 2. UART link (both boards stacked)

- [ ] The AP `/status` page shows `RF Node: OK 5658 MHz gain 40 …`.
- [ ] Change the channel in the web UI and save. The RF node retunes, which `/status` confirms.
- [ ] Reset only the RF node. The AP node reapplies the frequency and gain within about 1 s.
- [ ] With the Calibration tab open for 60 s, the `dropped` count stays at 0.

## 3. Coexistence

- [ ] Compare RF node noise-floor and gate-pass RSSI with the AP Wi-Fi idle and with a phone streaming the Calibration tab.
- [ ] If the AP radio desenses the receiver, lower `C5VRX_AP_TX_POWER` in `ap-node/lib/CONFIG/config.h`.

## 4. Gate LED strip

- [ ] Power the strip from its own 5 V supply. The idle state shows breathing blue.
- [ ] Set the LED count in the web UI. The whole ring lights, with no stale pixels past the end.
- [ ] Select the strip's **LED chip** and **colour order**. Idle shows pure blue, and the countdown shows pure red.
- [ ] With a phone streaming the Calibration tab (heavy Wi-Fi traffic), the ring shows no flicker or wrong-colour pixels toward its far end. That would mean RMT underruns.
- [ ] Press *Start Race*: the gate pulses red during the countdown and flashes green at the tone.
- [ ] Carry a VTX through the gate:
  - [ ] Idle: the meter fills.
  - [ ] Race running: the ring turns white while inside, and the lap chase plays.
- [ ] Unplug the RF node: the gate blinks purple within about 3 s.
- [ ] Repeat the desense check from §3 with the strip lit at the chosen brightness.

## 5. ELRS radio start

See [RADIO_START.md](RADIO_START.md) for the radio and backpack setup.

- [ ] In AP mode with *Radio start* on and a bind phrase saved, `/status` shows `ELRS Backpack: listening`.
  - [ ] If it doesn't, check the serial log for `ELRS:` errors. The STA MAC override (`esp_wifi_set_mac`) in `WIFI_AP_STA` mode and `esp_now_init` are the unproven steps on the C5 core.
  - [ ] Check whether the log says the STA protocol with `WIFI_PROTOCOL_LR` failed. If it did, record whether frames still arrive with b/g/n only.
- [ ] Phones and laptops still join the AP, and the web UI works, while ESP-NOW is listening on channel 1.
- [ ] A short press on the radio button starts the countdown, and a 1 s hold stops it, at gate distance and at the far end of the track.
- [ ] Count missed presses over 20 presses at the pilot's position.
- [ ] Repeat the RF node noise-floor check from §3 with ESP-NOW listening.

## 6. Field

- [ ] Tune the enter/exit thresholds and minimum lap time.
- [ ] Compare lap times against video frame timing. The target is ±100 ms.
- [ ] Confirm the XIAO battery-sense scaling (GPIO6/GPIO26) against a multimeter.

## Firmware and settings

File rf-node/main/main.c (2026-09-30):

/*
 * main.c - double-ESP-resso RF node.
 *
 * Measures 5.8 GHz carrier power on one FPV channel at 1 kHz and streams it
 * to the AP node over UART. The AP node owns the configuration; this node
 * stores the last frequency/gain in NVS so it keeps measuring on its own.
 *
 * SPDX-License-Identifier: GPL-3.0-or-later
 */
#include <stdio.h>

#include "esp_log.h"
#include "esp_timer.h"
#include "freertos/FreeRTOS.h"
#include "freertos/semphr.h"
#include "freertos/task.h"
#include "nvs.h"
#include "nvs_flash.h"

#include "node.h"
#include "rf_frontend.h"

#define DEFAULT_MHZ  5658u /* R1 */
#define RF_BOOT_MHZ  5865u /* Wi-Fi ch173: no phy_set_freq() needed */
#define DEFAULT_GAIN 40u
#define SAMPLE_PERIOD_MS 1u

static const char *TAG = "node";

/* Serializes PHY retune/gain writes against capture. */
static SemaphoreHandle_t s_rf_lock;
static volatile c5link_state_t s_state = C5LINK_ST_OK;

static volatile const char *s_stage = "reset";
static volatile uint32_t s_measure_ok;
static volatile uint32_t s_measure_err;
static volatile int s_last_err;

static nvs_handle_t s_trace = 0;
/* Non-zero when the previous boot hung inside a retune to this frequency. */
static uint16_t s_prev_hang_mhz;

void node_trace(const char *key)
{
    if (!s_trace) return;
    (void)nvs_set_u32(s_trace, key, (uint32_t)(esp_timer_get_time() / 1000));
    (void)nvs_commit(s_trace);
}

void node_trace_dump(void)
{
    printf("TRACE,prev_hang_mhz=%u\n", s_prev_hang_mhz);
    nvs_iterator_t it = NULL;
    esp_err_t res = nvs_entry_find(NVS_DEFAULT_PART_NAME, "trace", NVS_TYPE_ANY, &it);
    while (res == ESP_OK) {
        nvs_entry_info_t info;
        nvs_entry_info(it, &info);
        uint32_t u = 0;
        int32_t i = 0;
        uint16_t h = 0;
        if (nvs_get_u32(s_trace, info.key, &u) == ESP_OK)
            printf("TRACE,%s=%lu\n", info.key, (unsigned long)u);
        else if (nvs_get_i32(s_trace, info.key, &i) == ESP_OK)
            printf("TRACE,%s=%ld\n", info.key, (long)i);
        else if (nvs_get_u16(s_trace, info.key, &h) == ESP_OK)
            printf("TRACE,%s=%u\n", info.key, h);
        res = nvs_entry_next(&it);
    }
    nvs_release_iterator(it);
}

/* Retune guard: a flag in flash survives a hang, so the next boot knows the
 * previous retune never returned and does not repeat it automatically. */
static esp_err_t guarded_tune(uint16_t mhz)
{
    if (s_trace) {
        (void)nvs_set_u16(s_trace, "tuning", mhz);
        (void)nvs_commit(s_trace);
    }
    esp_err_t err = rf_frontend_tune(mhz);
    if (s_trace) {
        (void)nvs_erase_key(s_trace, "tuning");
        (void)nvs_commit(s_trace);
    }
    return err;
}

static void stage(const char *name)
{
    s_stage = name;
    ESP_LOGI(TAG, "boot: %s", name);
}

void node_diag(node_diag_t *out)
{
    out->stage = (const char *)s_stage;
    out->measure_ok = s_measure_ok;
    out->measure_err = s_measure_err;
    out->last_err = s_last_err;
}

static portMUX_TYPE s_latest_mux = portMUX_INITIALIZER_UNLOCKED;
static iq_power_t s_latest;
static uint32_t s_count;

static void settings_load(uint16_t *mhz, uint8_t *gain)
{
    *mhz = DEFAULT_MHZ;
    *gain = DEFAULT_GAIN;
    nvs_handle_t h;
    if (nvs_open("rfnode", NVS_READONLY, &h) != ESP_OK) return;
    uint16_t m;
    uint8_t g;
    if (nvs_get_u16(h, "mhz", &m) == ESP_OK && rf_frontend_can_tune(m)) *mhz = m;
    if (nvs_get_u8(h, "gain", &g) == ESP_OK && g <= C5LINK_MAX_GAIN) *gain = g;
    nvs_close(h);
}

static void settings_save(void)
{
    nvs_handle_t h;
    if (nvs_open("rfnode", NVS_READWRITE, &h) != ESP_OK) return;
    (void)nvs_set_u16(h, "mhz", rf_frontend_mhz());
    (void)nvs_set_u8(h, "gain", rf_frontend_gain());
    (void)nvs_commit(h);
    nvs_close(h);
}

void node_status(c5link_msg_t *status)
{
    *status = (c5link_msg_t){
        .type = C5LINK_MSG_STATUS,
        .mhz = rf_frontend_mhz(),
        .gain = rf_frontend_gain(),
        .state = s_state,
        .version = NODE_FW_VERSION,
    };
}

void node_apply(const c5link_msg_t *cmd, c5link_msg_t *status)
{
    switch (cmd->type) {
    case C5LINK_MSG_FREQ:
        if (!rf_frontend_can_tune(cmd->mhz)) {
            s_state = C5LINK_ST_ERR_FREQ;
            break;
        }
        if (cmd->mhz == rf_frontend_mhz() && s_state == C5LINK_ST_OK) break;
        xSemaphoreTake(s_rf_lock, portMAX_DELAY);
        s_state = C5LINK_ST_TUNING;
        esp_err_t err = guarded_tune(cmd->mhz);
        s_state = err == ESP_OK ? C5LINK_ST_OK : C5LINK_ST_ERR_RF;
        xSemaphoreGive(s_rf_lock);
        if (err == ESP_OK) settings_save();
        else ESP_LOGE(TAG, "tune %u failed: %s", cmd->mhz, esp_err_to_name(err));
        break;
    case C5LINK_MSG_GAIN:
        if (cmd->gain == rf_frontend_gain()) break;
        xSemaphoreTake(s_rf_lock, portMAX_DELAY);
        rf_frontend_set_gain(cmd->gain);
        xSemaphoreGive(s_rf_lock);
        settings_save();
        break;
    default:
        break;
    }
    node_status(status);
}

bool node_latest(iq_power_t *out, uint32_t *count)
{
    taskENTER_CRITICAL(&s_latest_mux);
    *out = s_latest;
    *count = s_count;
    taskEXIT_CRITICAL(&s_latest_mux);
    return *count != 0;
}

static void measure_task(void *arg)
{
    (void)arg;
    uint8_t seq = 0;
    TickType_t wake = xTaskGetTickCount();
    for (;;) {
        vTaskDelayUntil(&wake, pdMS_TO_TICKS(SAMPLE_PERIOD_MS));
        /* Skip samples while a retune/gain write owns the PHY, like the
         * RX5808 returning 0 during its tune time. */
        if (xSemaphoreTake(s_rf_lock, 0) != pdTRUE) continue;
        iq_power_t p;
        esp_err_t err = iq_power_measure(&p);
        xSemaphoreGive(s_rf_lock);
        if (err != ESP_OK) {
            s_measure_err = s_measure_err + 1;
            s_last_err = err;
            if (s_measure_err == 1) {
                node_trace("t51_meas_err");
                if (s_trace) (void)nvs_set_i32(s_trace, "t52_err_code", err);
            }
            continue;
        }
        s_measure_ok = s_measure_ok + 1;
        if (s_measure_ok == 1) node_trace("t50_meas_ok");
        if (s_measure_ok == 5000) node_trace("t53_meas_5k");
        if (s_state != C5LINK_ST_OK) continue;

        taskENTER_CRITICAL(&s_latest_mux);
        s_latest = p;
        ++s_count;
        taskEXIT_CRITICAL(&s_latest_mux);

        c5link_msg_t m = {.type = C5LINK_MSG_RSSI, .seq = seq++, .rssi = p.rssi};
        link_send(&m);
    }
}

void app_main(void)
{
    s_rf_lock = xSemaphoreCreateMutex();
    configASSERT(s_rf_lock);

    /* Console first: it must answer even if RF bring-up stalls. */
    console_start();
    stage("nvs");
    esp_err_t err = nvs_flash_init();
    if (err == ESP_ERR_NVS_NO_FREE_PAGES || err == ESP_ERR_NVS_NEW_VERSION_FOUND) {
        ESP_ERROR_CHECK(nvs_flash_erase());
        err = nvs_flash_init();
    }
    ESP_ERROR_CHECK(err);
    if (nvs_open("trace", NVS_READWRITE, &s_trace) == ESP_OK) {
        if (nvs_get_u16(s_trace, "tuning", &s_prev_hang_mhz) == ESP_OK) {
            /* Keep the previous boot's trace for 't', drop only the flag. */
            (void)nvs_erase_key(s_trace, "tuning");
            (void)nvs_commit(s_trace);
            ESP_LOGE(TAG, "previous boot hung retuning to %u MHz", s_prev_hang_mhz);
        } else {
            (void)nvs_erase_all(s_trace);
            node_trace("t02_nvs");
        }
    }

    uint16_t mhz;
    uint8_t gain;
    settings_load(&mhz, &gain);
    /* Bring RF up on the plain Wi-Fi center first; the saved channel may need
     * the experimental phy_set_freq() step, which runs last (boot_tune) so a
     * failure there cannot keep the console and link from starting. */
    stage("rf_frontend_start");
    ESP_ERROR_CHECK(rf_frontend_start(RF_BOOT_MHZ, gain));
    node_trace("t30_rf_ok");

    stage("iq_power_init");
    ESP_ERROR_CHECK(iq_power_init());
    node_trace("t31_iq_ok");

    stage("link_start");
    link_start();
    stage("running");
    node_trace("t40_running");
    xTaskCreate(measure_task, "measure", 4096, NULL, 5, NULL);

    if (s_prev_hang_mhz) {
        /* Stay on the bootstrap center; the AP can still request a retune. */
        s_state = C5LINK_ST_ERR_RF;
    } else if (mhz != rf_frontend_mhz()) {
        stage("boot_tune");
        c5link_msg_t tune = {.type = C5LINK_MSG_FREQ, .mhz = mhz}, status;
        node_apply(&tune, &status);
        stage("running");
    }
    ESP_LOGI(TAG, "RF node v%u running: %u MHz gain %u", NODE_FW_VERSION,
             rf_frontend_mhz(), rf_frontend_gain());
}

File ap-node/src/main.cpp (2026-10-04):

#include "debug.h"
#include "led.h"
#include "webserver.h"
#include <ElegantOTA.h>

#ifdef C5VRX_LINK
static C5Link rx(PIN_C5LINK_RX, PIN_C5LINK_TX);
#else
static RX5808 rx(PIN_RX5808_RSSI, PIN_RX5808_DATA, PIN_RX5808_SELECT, PIN_RX5808_CLOCK);
#endif
static Config config;
static Webserver ws;
static Buzzer buzzer;
static Led led;
static LapTimer timer;
static BatteryMonitor monitor;
#ifdef C5VRX_LINK
static RaceControl race;
#endif
#ifdef ELRS_BACKPACK
static ElrsBackpack elrs;

// Short press starts the countdown, long press stops or cancels it.
static void handleRadioButton(uint32_t currentTimeMs) {
    elrs_press_e press = elrs.handle(currentTimeMs, config.getElrsEnabled(), config.getElrsMac());
    elrs.debugStats(currentTimeMs);
    if (press == ELRS_PRESS_SHORT && race.isIdle()) {
        buzzer.beep(60);
        race.requestBegin();
    } else if (press == ELRS_PRESS_LONG && !race.isIdle()) {
        buzzer.beep(60);
        race.requestStop();
    }
}
#endif
#ifdef PIN_LED_STRIP
static LedStrip ledStrip;

static void handleGateLights(uint32_t currentTimeMs) {
    ledStrip.configure(config.getLedEnabled(), config.getLedCount(), config.getLedBrightness(), config.getLedType(), config.getLedOrder());
    ledstrip_inputs_t in = {};
    in.running = timer.isRunning();
    in.lapSerial = timer.getLapSerial();
    in.rssi = timer.getRssi();
    in.enterRssi = config.getEnterRssi();
    in.exitRssi = config.getExitRssi();
#ifdef C5VRX_LINK
    in.rfFault = !rx.healthy(currentTimeMs);
#endif
    in.batteryLow = monitor.isAlarming();
    ledStrip.handleLedStrip(currentTimeMs, in);
}
#endif

static TaskHandle_t xTimerTask = NULL;

static void parallelTask(void *pvArgs) {
    for (;;) {
        uint32_t currentTimeMs = millis();
        buzzer.handleBuzzer(currentTimeMs);
        led.handleLed(currentTimeMs);
        ws.handleWebUpdate(currentTimeMs);
        config.handleEeprom(currentTimeMs);
        rx.handleFrequencyChange(currentTimeMs, config.getFrequency());
#ifdef C5VRX_LINK
        rx.handleGainChange(currentTimeMs, config.getRfGain());
        rx.debugStats(currentTimeMs);
#endif
#ifdef ELRS_BACKPACK
        handleRadioButton(currentTimeMs);
#endif
#ifdef C5VRX_LINK
        race.handleRaceControl(currentTimeMs);
#endif
        monitor.checkBatteryState(currentTimeMs, config.getAlarmThreshold());
#ifdef PIN_LED_STRIP
        handleGateLights(currentTimeMs);
#endif
        buzzer.handleBuzzer(currentTimeMs);
        led.handleLed(currentTimeMs);
#ifdef C5VRX_LINK
        // Single-core C5: let the lap timer loop and the idle task run.
        vTaskDelay(1);
#endif
    }
}

static void initParallelTask() {
    disableCore0WDT();
#ifdef ELRS_BACKPACK
    // esp_now_init(), esp_wifi_set_mac() and the ELRS stats printf run on this task.
    xTaskCreatePinnedToCore(parallelTask, "parallelTask", 6144, NULL, 0, &xTimerTask, 0);
#else
    xTaskCreatePinnedToCore(parallelTask, "parallelTask", 3000, NULL, 0, &xTimerTask, 0);
#endif
}

void setup() {
    DEBUG_INIT;
    config.init();
    rx.init();
    buzzer.init(PIN_BUZZER, BUZZER_INVERTED);
    led.init(PIN_LED, LED_INVERTED);
    timer.init(&config, &rx, &buzzer, &led);
#ifdef PIN_VBAT_EN
    pinMode(PIN_VBAT_EN, OUTPUT);
    digitalWrite(PIN_VBAT_EN, HIGH);
#endif
    monitor.init(PIN_VBAT, VBAT_SCALE, VBAT_ADD, &buzzer, &led);
    ws.init(&config, &timer, &monitor, &buzzer, &led);
#ifdef C5VRX_LINK
    ws.setRssiSource(&rx);
    race.init(&config, &timer);
    ws.setRaceControl(&race);
#endif
#ifdef PIN_LED_STRIP
    ledStrip.init(PIN_LED_STRIP);
    ws.setLedStrip(&ledStrip);
#ifdef C5VRX_LINK
    race.setLedStrip(&ledStrip);
#endif
#endif
#ifdef ELRS_BACKPACK
    ws.setElrsBackpack(&elrs);
#endif
    led.on(400);
    buzzer.beep(200);
    initParallelTask();
}

void loop() {
#ifdef C5VRX_LINK
    // One lap timer update per 1 kHz RF node sample, not per loop pass.
    while (rx.poll()) {
        timer.handleLapTimerUpdate(millis());
    }
    ElegantOTA.loop();
    delay(1);
#else
    uint32_t currentTimeMs = millis();
    timer.handleLapTimerUpdate(currentTimeMs);
    ElegantOTA.loop();
#endif
}

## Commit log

2026-09-28 feat: two-board ESP32-C5 FPV lap timer (RF node + PhobosLT AP node)
    - rf-node: ESP-IDF v6.0.2 app derived from C5VRX. Receive-only 5.8 GHz
    frontend, 1 kHz MODEM_DIAG Q4/I4 power -> 0-255 RSSI, UART link, and a
    USB console for bring-up.
    - ap-node: PhobosLT fork with a XIAO_C5 env. The C5Link RSSI source
    replaces the RX5808, web UI changes retune the RF node, and the Wi-Fi AP
    is limited to 2.4 GHz.
    - common: two-way checksummed UART line protocol shared by both nodes.
    - Docs (hardware, protocol, bring-up), host tests, RSSI logging tool, CI.
    Not yet validated on hardware.
    [partitions.csv]
2026-09-28 feat(ap-node): WS2812B gate lights driven by race state
    Add a WS2812B strip on the AP node's D4 (GPIO23), driven by Adafruit
    NeoPixel over RMT from the parallel task at 50 Hz. Colours follow the race:
    - idle: breathing blue plus an RSSI meter
    - countdown: pulsing red (the browser posts the new /timer/arm)
    - start: green flash
    - running: green, white while the drone is in the gate
    - lap: white chase
    - RF node link down or error: purple
    - low battery: amber blip
    LED count, brightness cap and on/off are configurable in the web UI
    (CONFIG_VERSION 2). Docs cover wiring, the power budget for a 50 cm gate,
    and bring-up steps.
    [main.cpp]
2026-09-30 docs: add FLASHING.md with exact flashing steps for both boards
2026-09-30 fix(ap-node): build LittleFS image as disk version 2.0
    The ESP32-C5 Arduino core only mounts LittleFS disk version 2.0, but the
    platform builds 2.1 images by default. The firmware logged "Mounting
    LittleFS failed! Error: -1" and the web server answered "Handler did not
    handle the request". Set board_build.littlefs_version = 2.0 for XIAO_C5.
    Verified on hardware: the AP node now logs "LittleFS mounted sucessfully".
    FLASHING.md:
    - Use the underscore esptool syntax, which works on both v4 and v5.
    - Document that the UART must be wired straight (D6-D6, D7-D7).
2026-09-30 fix: first hardware bring-up of the RF node and the UART link
    The link, RF capture and RSSI stream now work on hardware.
    Link:
    - Move the UART link from D6/D7 to D5 (RF TX to AP RX) and D9 (AP TX to
    RF RX). GPIO11/12 are the ESP32-C5 UART0 console pins: both ROM boot logs
    and the Arduino console are driven out on GPIO11, which garbled the link.
    RF node:
    - Capture: replace the per-sample finite PARLIO receive, which starved the
    CPU after the first capture, with C5VRX's interrupt-free continuous ring
    and completed-descriptor window.
    - Memory: reserve the MAC dump SRAM window 0x40830000-0x4083FFFF from the
    heap, because the dump engine writes into it continuously.
    - Startup: bring R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
    [iq_power.c, link.c, main.c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]
2026-10-03 hardware: add FreeCAD model
    [double-ESP-resso.FCStd]
2026-10-03 feat(ap-node): start and stop races from an ExpressLRS radio button
    The ELRS TX backpack forwards the radio's DVR Rec AUX switch as MSP 0x0305
    over ESP-NOW. The AP node listens on the bind-phrase UID (STA MAC override,
    SoftAP pinned to channel 1): short press starts the countdown, a 1 s hold
    stops or cancels it.
    The start countdown moves into firmware (RaceControl) so the web button and
    the radio behave the same; the browser follows raceArm/raceStart/raceStop
    SSE events. Config v3 adds the ELRS UID and enable flag, migrating v2.
    [main.cpp]
2026-10-03 feat(ap-node): ELRS backpack diagnostics on /status and serial
    Count ESP-NOW frames at each step (on air via a promiscuous sniffer, delivered,
    from the bound UID, valid MSP, DVR recording state, classified presses), and
    report start errors, the actual STA MAC and channel. Documented in
    docs/RADIO_START.md troubleshooting.
    [main.cpp]
2026-10-03 fix(ap-node): default low-battery alarm to 0.0 V (off)
2026-10-04 feat(ap-node): drive WS2812B, WS2812 and WS2811 gate strips
    Send frames with our own RMT encoder (per-chip timing, two memory blocks,
    reset gap) instead of Adafruit's IDF 5 espShow, which ignores 400 kHz, is
    out of spec for WS2811 and underruns under Wi-Fi load. Add LED chip and
    colour order settings (config v4, v3 migrated) and a timing host test.
    [main.cpp]
2026-10-24 feat(ap-node): stream 1 kHz lap-timer RSSI over SSE at /rssi
    For a desktop app (logging, replay, calibration). loop() pushes every
    sample the lap timer used, raw and Kalman-filtered, into a lock-free SPSC
    ring (lib/RSSISTREAM/rssi_stream.h, plain C). parallelTask drains it only
    while a client is connected, in 50 ms batches, with race start/stop and
    lap marks on the same stream. Format in docs/protocol.md; host test in
    tests/test_rssi_stream.c.
2026-10-24 chore(ap-node): LED strip data on GPIO25, default RF gain 35
2026-10-24 feat(rf-node): raw I/Q band-power RSSI (FPVGate C5MK method)
    Replace the 4-bit MODEM_DIAG/PARLIO wideband capture with narrow-band
    power from raw 10-bit I/Q, following FPVGate C5MK's published method
    (paper and docs/RADIO_INTERNALS.md). Reimplemented from that
    description and our own disassembly of ESP-IDF v6.0.2's Apache-2.0
    libphy/librftest; no C5MK code is used (it is CC BY-NC-SA 4.0).
    - Wi-Fi with no interface plus promiscuous RX keeps the PHY powered.
    phy_set_chanfreq(5180, 1) calibrates the band once, then
    phy_set_rf_freq_offset() puts the LO 10 MHz below the pilot. The
    phy_param offsets (xtal byte 49, trim int16 at 30) were checked
    against IDF 6.0.2.
    - iq_dump.c: one stock ad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
2026-10-25 fix(ap-node): return the gate to idle when a countdown is stopped
    LedStrip keeps its own arming state, cleared only when the timer starts
    or 15 s after the last arm(). RaceControl::stop() never told it, so a
    countdown cancelled from the web UI or the radio left the gate in its
    countdown colour until the next race started. stop() now calls
    LedStrip::disarm().
2026-10-25 feat(ap-node): RotorHazard start sequence and gate colours
    Staging now follows RotorHazard's default race format. After "Arm your
    quad", three 100 ms staging tones play 1 s apart (new raceTone SSE
    event), then the 700 ms start tone a random 0.5-4 s after the last one.
    The browser plays RH's 440/880 Hz triangle tones, and the buzzer the
    same pattern, whichever startTone selects.
    Race-event gate colours follow RH's default LED effects, with the
    latest event replacing the previous one:
    - staging: orange, two on one off
    - start: green for 4 s
    - stop, including a cancelled countdown: red for 4 s
    - gate entry while racing: seat-1 blue sparkle
    - power-up: rainbow cycle
    Idle and running green stay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
2026-10-25 feat(ap-node): bouncing balls as the idle gate effect
    Replaces breathing blue. Four balls (yellow, orange, purple, blue) fall
    onto LED 0 under gravity and lose speed at each bounce, at different
    rates, then relaunch to full height. They restart cleanly after a
    race. Like WLED's effect but written from scratch (WLED is EUPL). The
    RSSI level meter still draws over it.
2026-10-25 feat: move the buzzer to D0 and the RF link to D1 to free the XIAO SPI pins
    The AP node's microSD card needs D8-D10, the XIAO's SPI pins. D8 was the
    buzzer and D9 the AP->RF UART link. The buzzer moves to D0, and the link
    moves to D1 on both boards, so the joined stack pins are now 5V, GND, D1
    and D5. D9 must no longer be joined. Older stacks must be rewired and both
    boards reflashed.
    Also corrects the LED strip pin comment and docs to D2 (GPIO25), where
    PIN_LED_STRIP already pointed.
2026-10-25 feat(ap-node): 1 kHz RSSI logging to a microSD card
    A microSD card on the XIAO SPI pins (SCK D8, MISO D9, MOSI D10, CS D4)
    logs every lap-timer sample while the new Config-tab flag is on. The flag
    is config v6 sdLog, off by default and migrated without a reset.
    - lib/SDLOG/sdlog_row.h (plain C, host-tested): a lock-free 2048-sample
    ring filled by loop(), and fixed-width 29-byte CSV rows (ms, raw,
    filtered, race start/stop/lap event, lap_ms).
    - A writer task drains the ring into one numbered file per session and
    saves it every second, so card stalls never block lap timing.
    Mounting is retried while no card is present.
    - /sdlog/export?min=15 binary-searches the newest file for the win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
2026-10-25 feat(ap-node): show whether the SD card is present and ready
    The card used to be mounted only while logging was on. The writer task
    now mounts it at boot, retries every 5 s while missing, and reads sector
    0 every 5 s while idle, so a pulled card is noticed. When SD.begin()
    fails, initialising the card without mounting it (sdcard_init +
    disk_initialize) separates "no card" from "card without FAT", which
    includes exFAT, as this core is built without it.
    /status gains an "SD Card:" line (OK with type, size and free space, or
    the error), and the logging state moves to "SD Logging:". The Config tab
    shows both under the logging checkbox, with the card state in green or
    red.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
2026-10-28 feat: send the capture's clip per mille on R lines
    R lines become R,<seq>,<rssi>,<clip>. clip is the RF node's clip_permille
    capped at 255, so the AP node can tell a strong pass from one that clipped
    the 10-bit I/Q ADC. The parser still accepts the 3-field line from RF
    firmware 2 (clip = 0) and now rejects a trailing comma. RF firmware 3.
    The AP node's C5Link keeps the last clip value and exposes the RF node's
    reported gain (currentGain / gainApplied) for the calibrator.
2026-10-28 feat(ap-node): auto-calibration state machine with host tests
    lib/CALIBRATION/calibration.h is plain C99 and header-only, like
    rssi_stream.h. It is fed one Kalman-filtered sample per 1 kHz RF sample and
    tells the caller which gain to apply.
    - Phase A starts at gain 45 and steps the gain down after every pass that
    clips (clip > 5 per mille) or has no headroom (filtered peak > 230). It
    locks the first gain with 2 clean passes in a row.
    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
2026-10-28 feat(ap-node): run auto-calibration from the lap timer loop
    - loop() feeds the calibrator the lap timer's filtered RSSI, the link's clip
    value and whether the RF node reports the requested gain.
    - While calibration runs, parallelTask sends the calibrator's gain instead of
    the configured one. On success the gain, Enter and Exit are written to
    config once, and handleEeprom saves them.
    - POST /calib/start (optional {"startGain","laps"}) and /calib/stop only set
    request flags. loop() runs cal_start / cal_abort, so the 18 KB struct is
    never reset while cal_push writes it. Start is refused with 409 while a
    race runs or counts down.
    - GET /calib returns the state, the current event and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
2026-10-28 feat(ap-node): Auto calibrate button with voice prompts
    The Calibration tab gets Auto calibrate / Stop, the start gain and the
    number of laps, and a status line. Starting turns voice on, posts
    /calib/start and polls GET /calib every 250 ms. Each new event in the
    event log is spoken once, in order, and when calibration finishes the
    Enter/Exit sliders and the RF gain are reloaded from /config (the firmware
    has already saved them). A page loaded mid-calibration follows it without
    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
2026-10-28 docs: auto-calibration usage, endpoints and design notes
    - README "Using it": Auto calibrate with voice, and aiming the antenna
    across the gate.
    - protocol.md: the R line's clip field and a Calibration endpoints section.
    - CLAUDE.md: an Auto-calibration decision bullet (why gain, why real passes,
    phases A/B, loop-task integration) with its unproven parts, including the
    risk of a between-pass bump being taken for a gate pass in phase A.
    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
2026-10-28 feat(ap-node): colour twinkles as the idle gate effect
    Replaces the bouncing balls. On a dark ring, random LEDs fade up to a
    random yellow, red, pink or purple and back off. New twinkles start at a
    steady 5 % of the LEDs per second, each rising in 0.6 s and fading out
    over about 1.7 s, slowing as it dims. That lights about 4 full-LED
    equivalents on average on 94 LEDs, against about 11 for a fairy-lights
    glow, which keeps idle power low. The RSSI level meter still draws on
    top.
    Like WLED's Colortwinkles but written from scratch (WLED is EUPL).
2026-10-29 fix(ap-node): keep idle twinkles going after a late frame
    renderTwinkles() cleared every twinkle whenever more than 500 ms had passed
    since its last frame, meant for coming back from a race or another effect.
    A starved parallelTask produced the same gap, so the gate froze mid-fade,
    went dark and started over. Twinkles now restart only when the previous
    frame showed something else (an effect, a race, a dark strip).
    LED frame gaps over 200 ms are logged on the debug console to find what
    starves parallelTask.
2026-10-29 fix(ap-node): run the SD writer task at parallelTask's priority
    With no card, or no SD module (MISO floating), the Arduino SD driver's
    sdWait() spins on SPI for up to 500 ms per call, and mount() plus
    probeCard() retry every 5 s. At priority 1 the writer starved parallelTask
    (priority 0) on the single-core C5, which stalls the gate LEDs, buzzer and
    web updates. At priority 0 FreeRTOS time-slices the two every tick, and
    the lap timer loop (priority 1) still comes first.
2026-10-29 feat(ap-node): Mount / Unmount SD card buttons, no automatic retries
    The AP node no longer retries a missing card every 5 s. It mounts once at
    boot, and after that only from the Config tab's Mount SD card button
    (POST /sdlog/mount). Unmount SD card (POST /sdlog/unmount) closes the log
    file and unmounts, so the card can be taken out to read the logs without
    rebooting the gate; put it back and press Mount, and logging starts a new
    file.
    - Unmount waits for an export download still reading the card. openExport
    takes a lease that closeExport, or the Cursor destructor for a dropped
    download, gives back.
    - A mounted idle card is still checked every 5 s, so pulling it without
    unmounting show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
2026-10-29 feat(ap-node): radio button can start auto-calibration
    Config v7 adds elrsAction. With ELRS_ACTION_CALIBRATE, a short press of
    the ELRS radio button starts auto-calibration instead of the race
    countdown, and a long press stops it. The press sets a flag that loop()
    carries out, as for /calib/start, using the start gain and laps last used
    from the web UI (45 and 3 after boot).
    handleWebUpdate sends a calibStart SSE event whenever a calibration
    starts, so an open page can follow one it didn't start.
2026-10-29 feat(ap-node): Radio button starts setting and voice for radio calibration
    The Config tab's ELRS section gets "Radio button starts: Race / Auto
    calibration". On the calibStart event an open page follows the
    calibration and speaks its prompts from "started" on, skipping the
    previous run's events. A page that started it itself is not disturbed.
    Docs: RADIO_START.md (Calibrate from the radio), protocol.md, VOICE.md,
    CLAUDE.md and a bring-up check.
